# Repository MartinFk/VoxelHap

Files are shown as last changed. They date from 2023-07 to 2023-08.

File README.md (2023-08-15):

# VoxelHap

VoxelHap is an open-source toolkit, aiming to support VR researchers and developers in constructing highly functional proxy objects providing tactile and kinesthetic haptic feedback. It consists of Voxels and Plates: (1) Voxels are blocks with special functionalities that form the core of each physical proxy, (2) Plates increase a proxy's haptic resolution, such as its shape, texture or weight. Beyond providing physical capabilities to realize haptic sensations, VoxelHap utilizes VR illusion techniques to expand its haptic resolution.

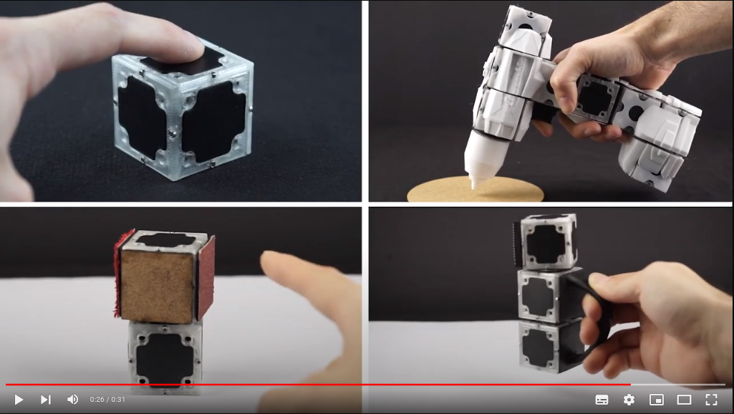
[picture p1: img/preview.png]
VoxelHap (https://youtu.be/_2FG0eMlGLQ "VoxelHap")


This work is provided under a MIT License. 

Please adequately cite this work, and show us your amazing projects! VoxelHap was published at the UIST'23 conference.

```
@inproceedings{feick2023VoxelHap,
author = {Feick, Martin and Biyikli, Cihan and Gani, Kiran and Wittig, Anton and Tang, Anthony and Krüger, Antonio},
title = {VoxelHap: A Toolkit for Constructing Proxies Providing Tactile and Kinesthetic Haptic Feedback in Virtual Reality},
year = {2023},
isbn = {979-8-4007-0132-0/23/1},
publisher = {Association for Computing Machinery},
address = {New York, NY, USA},
url = {https://doi.org/10.1145/3586183.3606722},
doi = {10.1145/3586183.3606722},
booktitle = {Proceedings of the 36nd Annual ACM Symposium on User Interface Software and Technology},
location = {San Francisco, CA, USA},
series = {UIST '23}
}
```

## Voxels
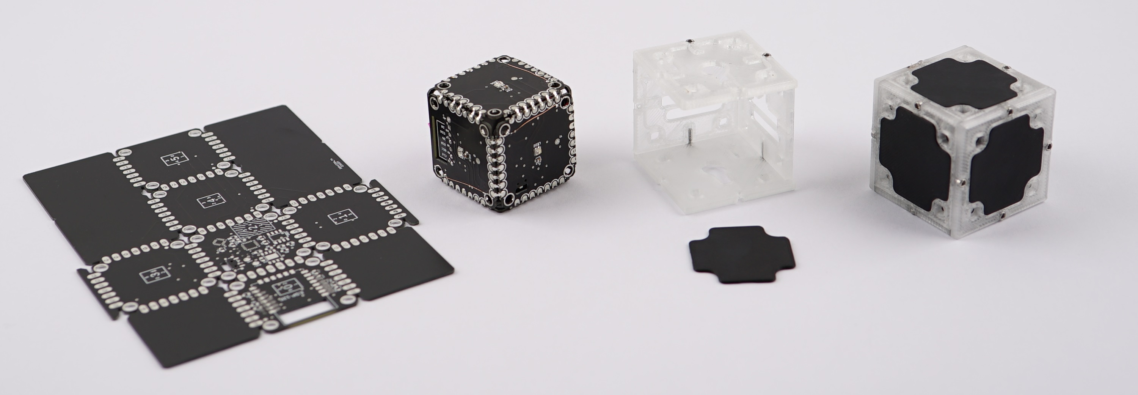
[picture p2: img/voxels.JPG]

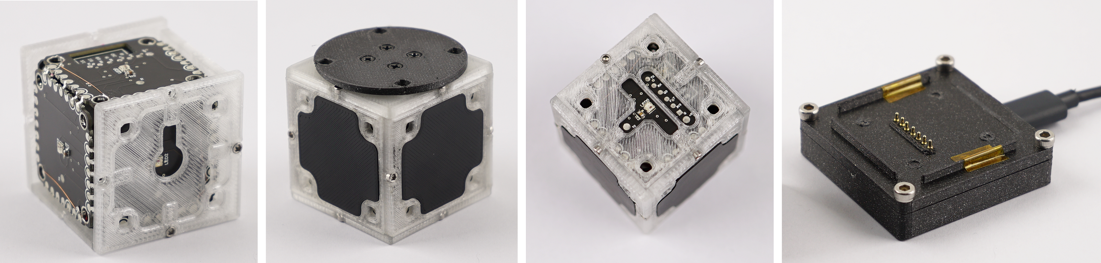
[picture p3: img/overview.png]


---------------------------------------------------------------------------------------------



## Communication

Voxels communicate using a Master/Slave architecure. Master (Wemos D1 mini) is connected to a host maschine via serial port running Unity3D. BaseVoxels (slaves) communicate to the master wirelessly using PainlessMesh.

The firmware folder contains the arduino files. Master.ino should be uploaded onto the master (Wemos D1 mini), and Slave_VoxelHap_Cubes.ino onto the BaseVoxels.



## PCB

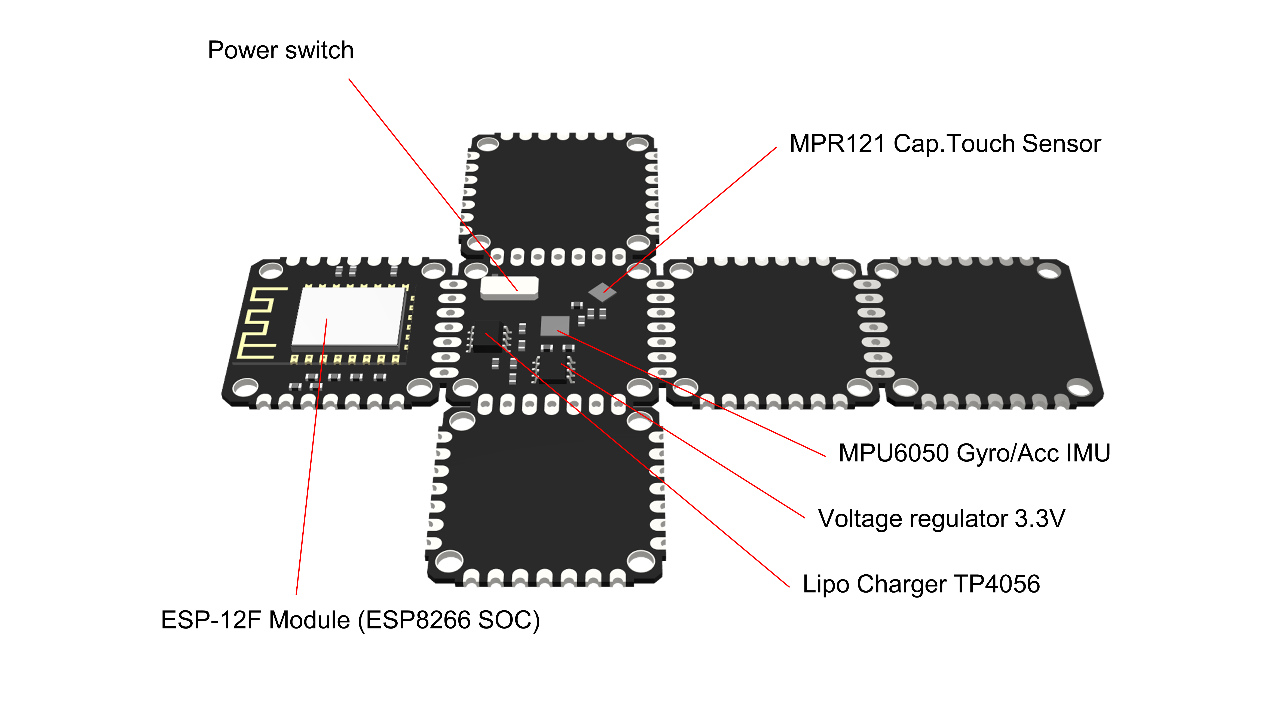
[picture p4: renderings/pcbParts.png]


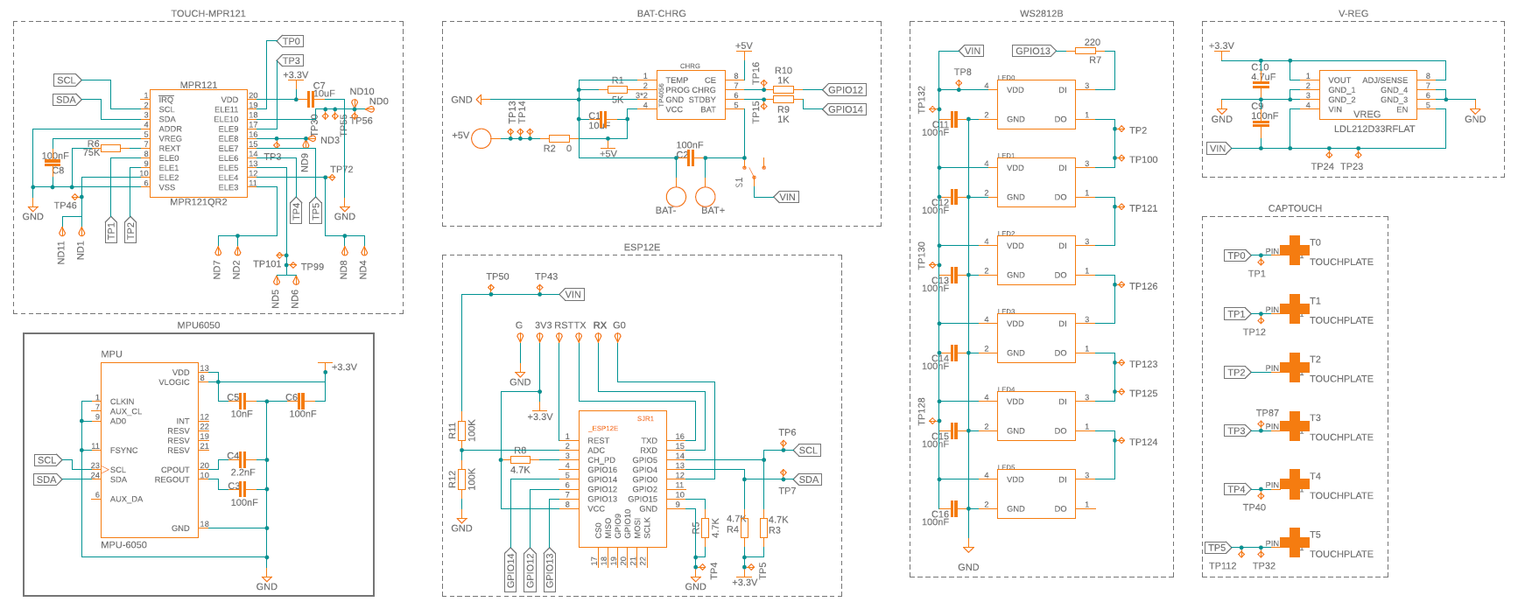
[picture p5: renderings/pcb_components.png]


## Dependencies 

(1) Voxels use a capacitive touch sensor MPR121. Download Adafruit_MPR121 libray from Arduino IDE. -> https://learn.adafruit.com/adafruit-mpr121-12-key-capacitive-touch-sensor-breakout-tutorial/wiring

(2) Voxels require FastLED library to manage LEDs on board. Download FastLED library from Arduino IDE. -> https://fastled.io/

(3) Voxels require ArduinoJson library to send JSON file to the master. Download ArduinoJson library from Arduino IDE. -> https://arduinojson.org/

(4) For Master/Slave communication between Voxels and the master Wemos D1, we use the PainlessMesh library. Download Painlessmesh library from Arduino IDE, specifically namedmesh example. -> https://gitlab.com/painlessMesh/painlessMesh/-/tree/develop/examples/namedMesh?ref_type=heads

(5) For Unity- Master communication establish Serial communication and import the Unity3D package (with .Net4.x frame work in player settings).

## Issues

If you face any problems while using the toolkit, please open an issue here - https://github.com/MartinFk/VoxelHap/issues or contact us under martin.feick@dfki.de 📫.

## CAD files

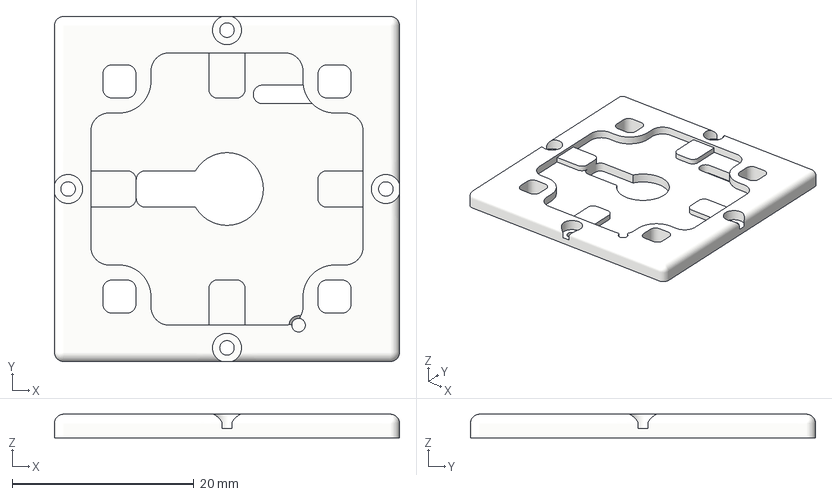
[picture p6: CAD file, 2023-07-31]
CAD files/TOP_SHELL.3mf
38.0 x 38.0 x 2.60 mm

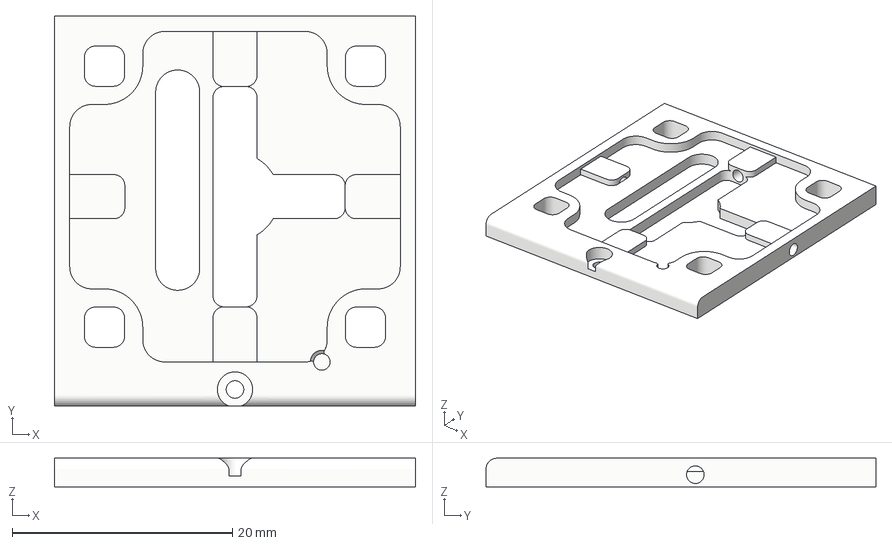
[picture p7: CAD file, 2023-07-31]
CAD files/SIDE_SHELL.3mf
32.8 x 35.4 x 2.60 mm

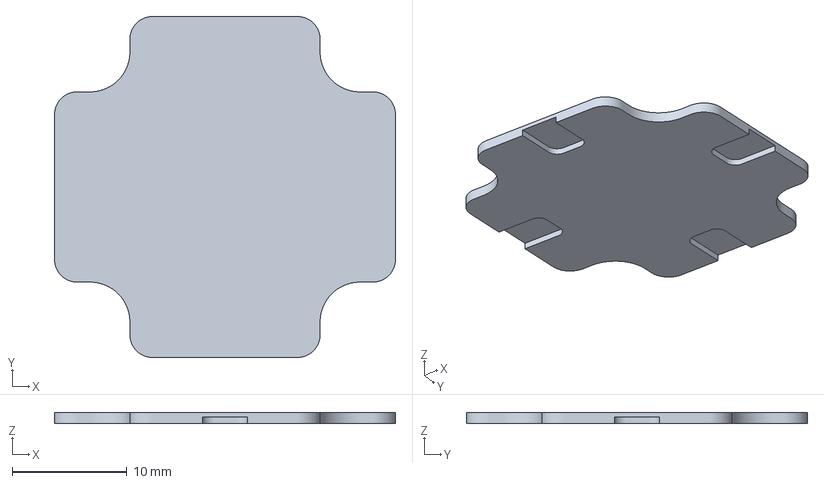
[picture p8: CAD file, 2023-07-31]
CAD files/TOUCHPLATE.3mf
29.7 x 29.7 x 0.99 mm

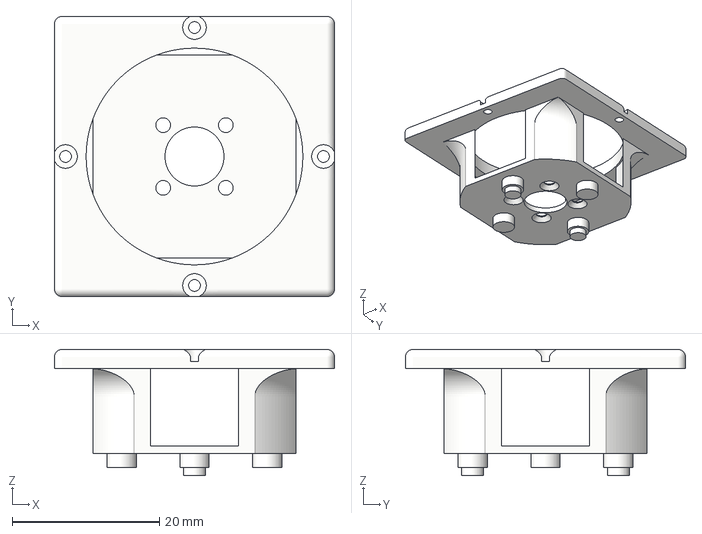
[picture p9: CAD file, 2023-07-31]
CAD files/ROT_TOP_SHELL.3mf
38.0 x 38.0 x 17.1 mm

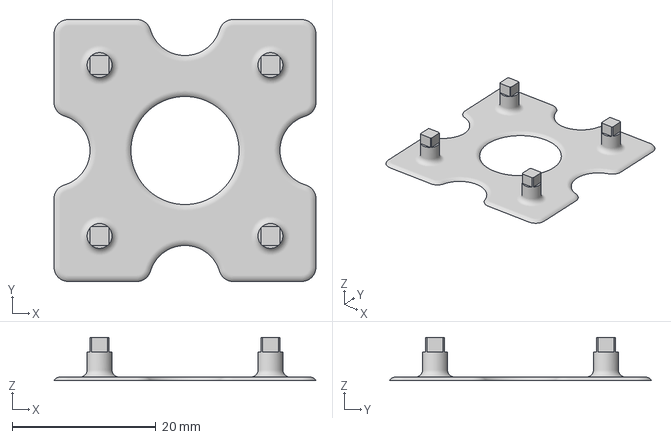
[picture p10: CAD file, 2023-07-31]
CAD files/CONNECTION_PLATE.3mf
36.4 x 36.4 x 6.00 mm

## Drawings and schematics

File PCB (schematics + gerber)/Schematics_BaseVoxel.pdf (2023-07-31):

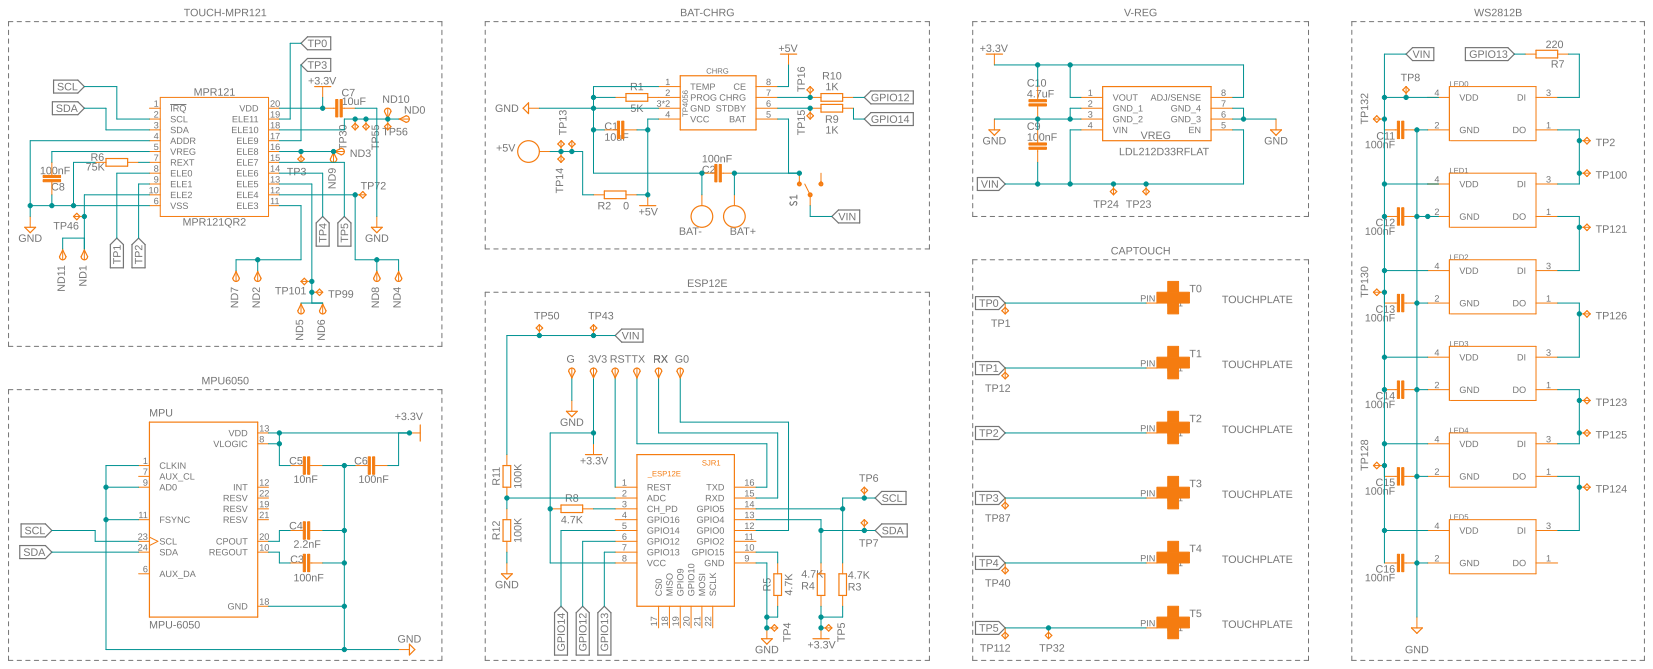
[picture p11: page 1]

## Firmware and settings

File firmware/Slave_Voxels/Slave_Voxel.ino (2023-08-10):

/*
This code works based on painless mesh. 

1. It connects to the master and Master acknowledges back with "Connected " from master.
2. Once it is connected to master( i.e. connection_flag=1 and light tuirn on cyan) , it sends the capacitance touch values to master. 
3. Every time there is a change in the capacitance touch, sends data to Master touched -1, relesed -0.
 -- Touch_status[12] saves the staus of each capacitance value.
 --  Here touch values 0,1,6,9,7,11 are mapped to the sides of the cubes to detect touch by the user and rest are mapped to see whether there is connection plate. 
4. We also send Cube_id to identify which cube is connected. For example now cub_id is 1 for cube 1. For example Base_Cube 1, doc["12"]=1; Base_Cube 2 doc["12"] = 2;


*/


#include <Wire.h>
#include "Adafruit_MPR121.h"
#ifndef _BV
#define _BV(bit) (1 << (bit)) 
#endif


#include "namedMesh.h"
#define   MESH_SSID       "whateverYouLike"
#define   MESH_PASSWORD   "somethingSneaky"
#define   MESH_PORT       5555
#include <ArduinoJson.h>



#include <FastLED.h>

#define NUM_LEDS        6
#define LED_TYPE      NEOPIXEL
#define COLOR_ORDER     GRB
#define DATA_PIN        13
#define BRIGHTNESS      255

CRGB leds[NUM_LEDS];


// You can have up to 4 on one i2c bus but one is enough for testing!
Adafruit_MPR121 cap = Adafruit_MPR121();



// Keeps track of the last pins touched
// so we know when buttons are 'released'
uint16_t lasttouched = 0;
uint16_t currtouched = 0;

// to control your personal task
Scheduler     userScheduler; 
namedMesh  mesh;
String msg =  String("hi");
String to = "Master";


// Name needs to be unique
// also change the cube_id,  value of variable doc[12].
 
String nodeName = "Base_Cube";
int cube_id =1;

void sendMessage() ;
Task taskSendMessage( TASK_SECOND * 0.3 , TASK_FOREVER, &sendMessage );

// indicates whether it is connected to master or not
int connection_flag=0;


bool a[12];
int t_flag=0;
const size_t CAPACITY = JSON_ARRAY_SIZE(3);
 
// allocate the memory for the document
StaticJsonDocument<CAPACITY> doc;

// create an empty array
JsonArray array = doc.to<JsonArray>();



// To store all capacitance touch values
int Touch_status[12]= {0,0,0,0,0,0,0,0,0,0,0,0};


void sendMessage() 
{   
  
  
  if(connection_flag==1)
    {
      DynamicJsonDocument doc(1024) ;
      currtouched = cap.touched();
	  
	  
      for (uint8_t i=0; i<12; i++) 
      {
        msg="";
        t_flag=0;
		
        // it if *is* touched and *wasnt* touched before, alert!
        if ((currtouched & _BV(i)) && !(lasttouched & _BV(i)) ) 
        {
            Touch_status[i]=1;
            a[i]= true;
            t_flag=1;
          
        }
		
        // if it *was* touched and now *isnt*, alert!
        if (!(currtouched & _BV(i)) && (lasttouched & _BV(i)) ) 
        {
            Touch_status[i]=0;
            a[i]=false;
            t_flag=1;
           
        }
        // Flag to see is any change in the touch status 
        if(t_flag==1)
        {  
            for (uint8_t i=0; i<12; i++)
            doc[String(i)]=Touch_status[i];
            doc["12"]= cube_id;;
            serializeJson(doc,msg);
            mesh.sendSingle(to,msg);
            Serial.println(msg);
        }
    
      }
  
      lasttouched = currtouched;
       
    } 
  };

void setup() {
  
      Serial.begin(115200);
	  
      if (!cap.begin(0x5A)) 
      {
        Serial.println("MPR121 not found, check wiring?");
        while (1);
      }
	  
	  // Fast LED setup
      FastLED.addLeds<NEOPIXEL, DATA_PIN>(leds, NUM_LEDS);
      FastLED.setBrightness(BRIGHTNESS);
	  
	  // Mesh initialisation, for more plesae named mesh example from painlessmesh 
	  
      mesh.init(MESH_SSID, MESH_PASSWORD, &userScheduler, MESH_PORT);
      mesh.setName(nodeName);                                                    // This needs to be an unique name! 
      mesh.onReceive([](uint32_t from, String &msg) { });

        mesh.onReceive([](String &from, String &msg) 
        {
            Serial.printf("Received message by name from: %s, %s\n", from.c_str(), msg.c_str());
            if(String(msg.c_str())=="Connected")
            {
            
            leds[4] = (CRGB::Cyan);
            FastLED.show(); 
            connection_flag=1;
			
         }
            
         });
          
          userScheduler.addTask(taskSendMessage);
          taskSendMessage.enable();

          
    }

void loop() 
{
  mesh.update();
}

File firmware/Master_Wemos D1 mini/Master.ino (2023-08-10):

//************************************************************
// This is a simple example that uses the painlessMesh library
// 
// This the master which recieves and sends information to the base cubes.
// Whenver a new cube connects it sends message to the cube and also write on serial port to communicate with Unity. 
// Comminicate the capacitance touch values sent by Base cube to unity 
// Every cube has a physical id and it is unique
// Physical id of the base Cube 3194200704  

//************************************************************


#include "namedMesh.h"
#define   MESH_SSID       "whateverYouLike"
#define   MESH_PASSWORD   "somethingSneaky"
#define   MESH_PORT       5555


Scheduler     userScheduler; // to control your personal task
namedMesh  mesh;
SimpleList<uint32_t> nodes;
String nodeName = "Master"; // Name needs to be unique
void newConnectionCallback(uint32_t nodeId);


uint32_t flag=0;
uint32_t connecetd_flag=0;
int j=0;
String a;

/*  Physical id of the base Cube 3194200704  */

Task taskSendMessage( TASK_SECOND, TASK_FOREVER, []() {
	
           // Serial.printf("--> startHere: New Connection, nodeId = %u\n", flag);
           String x = "";
		   
		   
		   
           if(flag !=0)
           {
                //Serial.printf("--> startHere: New Connection, nodeId = %u\n", flag);
                if (int(flag-3194200704) ==0)
                x = " Base_Cube";
                Serial.println(x);
				
				// Send message to the base cube acknowledging the connection
                String msg = String("Connected");
                String to = x;
                mesh.sendSingle(to, msg);
                flag= 0; 
				
           }
      
              
  }); 



void setup() 

{
  
      Serial.begin(115200);
      mesh.init(MESH_SSID, MESH_PASSWORD, &userScheduler, MESH_PORT);
      mesh.setName(nodeName); // This needs to be an unique name! 
  
  
  
     // Recieving the trouch values from the cubes after the connection is established 
      mesh.onReceive([](String &from, String &msg) 
      {
          DynamicJsonDocument doc(1024) ;
          deserializeJson(doc,msg.c_str());
		  
		  // Sending capacitance touch values to Unity
          for (uint8_t i=0; i<12; i++)
          {
            
			j = doc[String(i)];
            Serial.print(j);Serial.print(",");
          }
		  
          j = doc[String(12)];
          Serial.print(j);
          Serial.println();
      });
      
      // Detecting the base cube connection
      mesh.onChangedConnections([]() 
      {
          nodes = mesh.getNodeList();
          SimpleList<uint32_t>::iterator node = nodes.begin();
          while (node != nodes.end()) 
          {
             
             flag= *node;
             node++;
          }
           
       });
        
       userScheduler.addTask(taskSendMessage);
       taskSendMessage.enable();

}

void loop() 
{
  
    mesh.update();
     
}
